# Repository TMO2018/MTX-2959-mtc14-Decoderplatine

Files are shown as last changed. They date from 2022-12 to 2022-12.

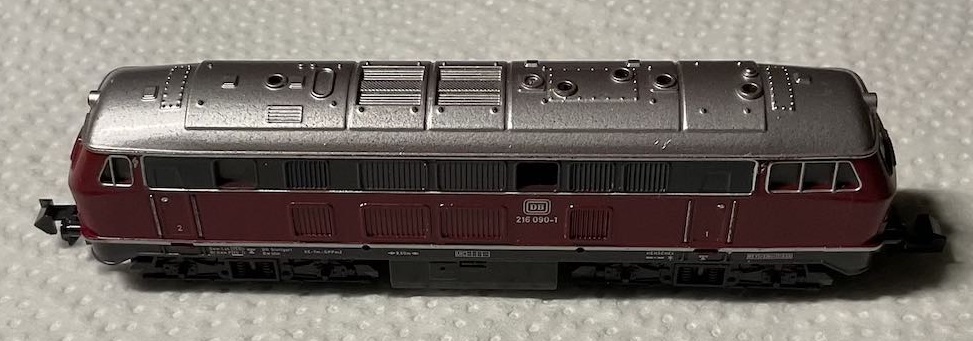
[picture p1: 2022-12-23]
kicad/Rev1_0/doc/pic/1.jpg

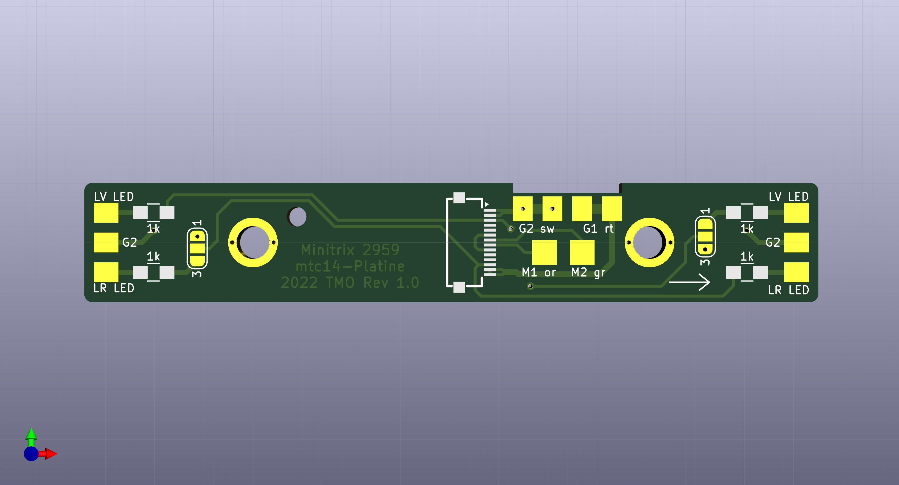
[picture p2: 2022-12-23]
kicad/Rev1_0/pic/front.jpg

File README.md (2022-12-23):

# MTX-2959-mtc14-Decoderplatine
Minitrix 2959 Decoderplatine mit mtc14-Schnittstelle

In diesem Projekt ist eine Digitalplatine mit mtc14-Digitalschnittstelle für die Minitrix Diesellok BR 216 090-1 (2959) beschrieben.
Diese Platine ersetzt 1:1 die vorhandene Platine und bietet zusätzlich eine Möglichkeit zum Anschluß von LED’s für Front- und Rückbeleuchtung.

Die Gerberdateien zur Herstellung der Platine befinden sich im kicad-Ordner (zip-Datei).







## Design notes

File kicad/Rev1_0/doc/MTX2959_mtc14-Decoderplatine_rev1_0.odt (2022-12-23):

MTX 2959 mtc14-Decoderpaltine Rev. 1.0

Beschreibung

# Einführung

In diesem Projekt ist eine Digitalplatine mit mtc14-Digitalschnittstelle für die Minitrix Diesellok BR 216 090-1 (2959) beschrieben.

Diese Platine ersetzt 1:1 die vorhandene Platine und bietet zusätzlich eine Möglichkeit zum Anschluß von LED’s für Front- und Rückbeleuchtung.

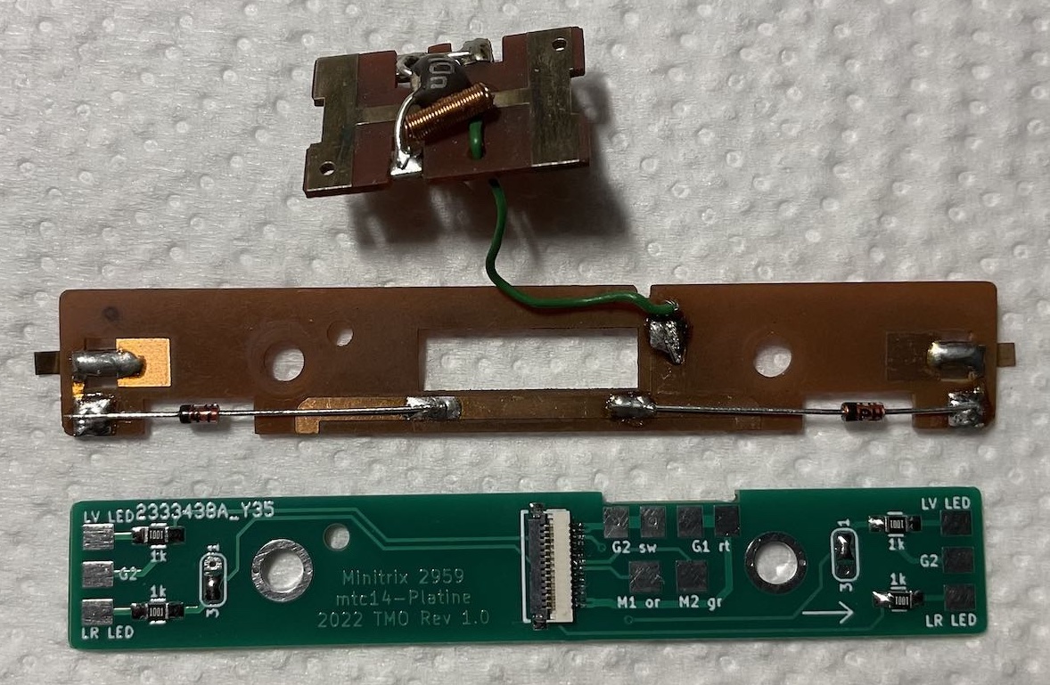
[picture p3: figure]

Achtung:

Die Platinendicke muß 1,0 mm betragen !

# Einbau

Es ist notwendig den Motor mit Litzen an die Lötpunkte M1 und M2 anzuschließen. Die Drossel kann in der Regel verbleiben. Wichtig ist dabei, dass zwischen Motor und Chasis sowie sonstigen leitfähigen Teilen keine Verbindungen bestehen.

Die Gleisspannung wird an den Lötpunkten G1 und G2 angeschlossen. G2 wird bei dieser Lok über die Achsen der Drehgestelle auf das Metallchassis und über die Schraubbefestigung auf die Platine übertragen.

Die kleine Platine aus dem Bodenbereich des Chassis wird weiterhin zur Stromversorgung genutzt. Anschluß an Lötpunkt G1. Ggf. ist der Kondensator je nach Regelverhalten der Decoders zu entfernen.

G2 ist mit dem Metallchassis verbunden.

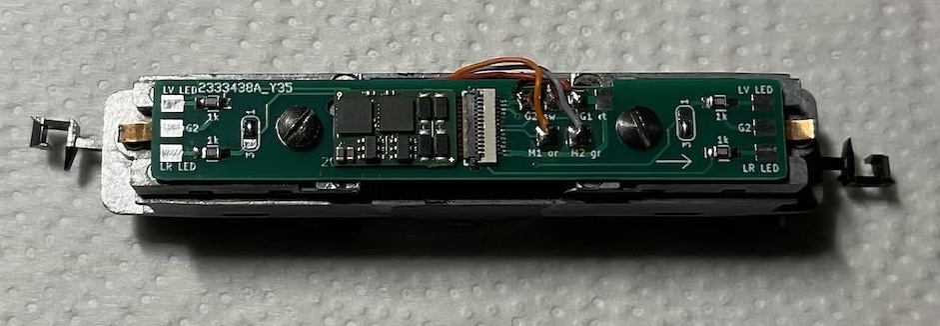
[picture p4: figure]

Lok mit Originalbeleuchtung


# Beleuchtung

Original:

Auf der Unterseite der Digitalplatine befinden sich rechts und links je eine Lötfläche an denen Metallzungen angelötet werden können um die vorhandene Glühlampen weiterhin zu nutzen,

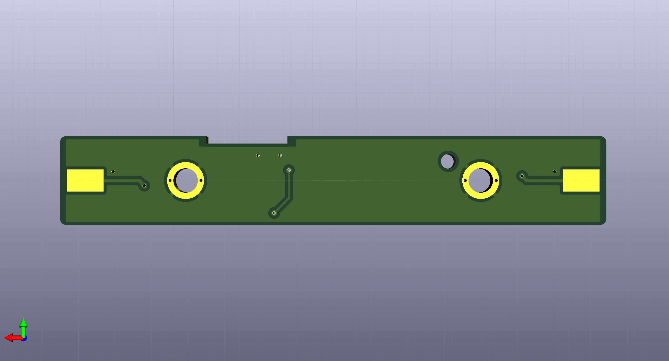
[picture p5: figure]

LED:

Falls die Originalbeleuchtung durch LED ersetzt wird, befinden sich auf der Oberseite der Digitalplatine Lötpunkte für Vorwärts- (LV) und Rückwärtsfahrt (LR). G2 ist der gemeinsame Rückleiter.


Mit den Löt-Jumpern wird die Beleuchtungs-Varinate ausgewählt.

Löt-Jumper neben Fahrtrichtungspfeil:

Brücke 1 nach Mitte: LED

Brücke 3 nach Mitte: Glühlampen

Löt-Jumper ohne Fahrtrichtungspfeil:

Brücke 1 nach Mitte: Glühlampen

Brücke 3 nach Mitte: LED

BOM

Reference Value Package Manufacturer Part

R1, R2, R3, R4 1k SMD 0805 Widerstand

J1 0.5K-QX-14PWB FPC / FFC HDGC Verbinder

Verbinder J1:

Fahrzeugseitig werden FPC / FFC Verbinder vom Typ AVX 6238 oder ähnlich verwendet. Für die Einhaltung der Norm ist entscheidend, dass die verwendeten Klemmleisten für 0,3 mm starkes Platinenmaterial spezifiziert sind, ein Anschlussraster von 0,5 mm und nur einseitig Kontakte haben.

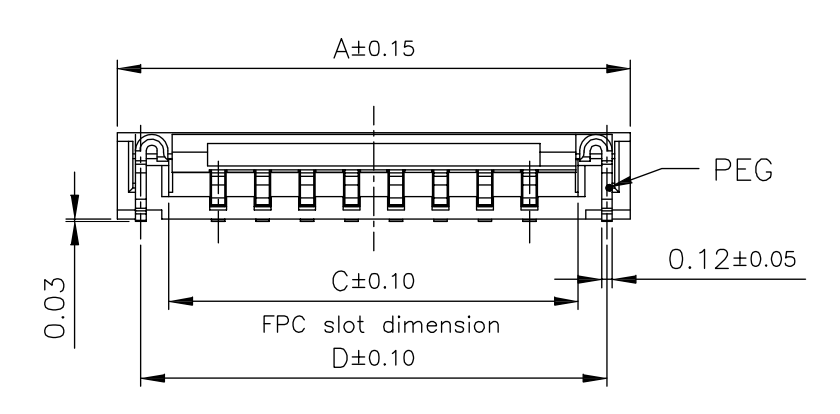
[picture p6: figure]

Das Maß C muß 7,60 mm betragen !

# Verbinder-Spezifikation:

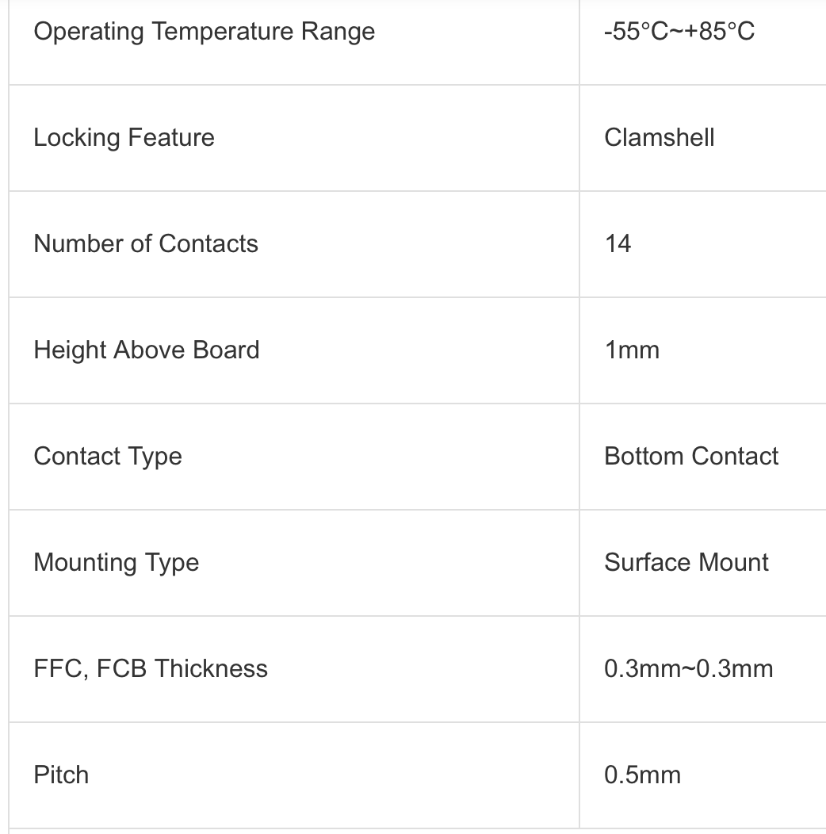
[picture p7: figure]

# Versionsinformation :

Revision 1.0:

Erste Version

MTX2959_mtc14-Decoderplatine_rev1_0.odt 23.12.2022 Page 6 of 6 TMO Version 1.0

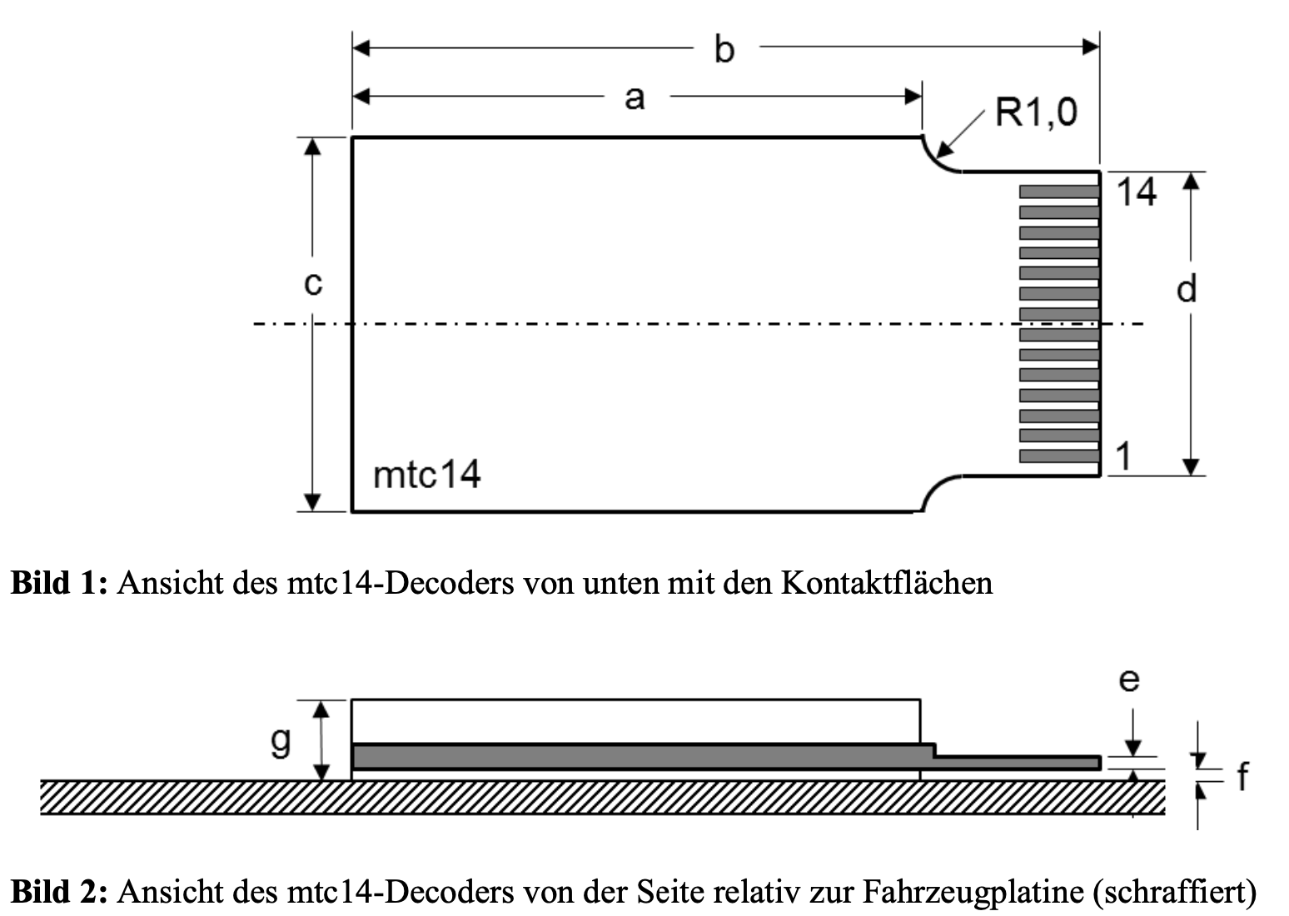
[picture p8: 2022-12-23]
kicad/Rev1_0/pic/mtc14-Decoder.png

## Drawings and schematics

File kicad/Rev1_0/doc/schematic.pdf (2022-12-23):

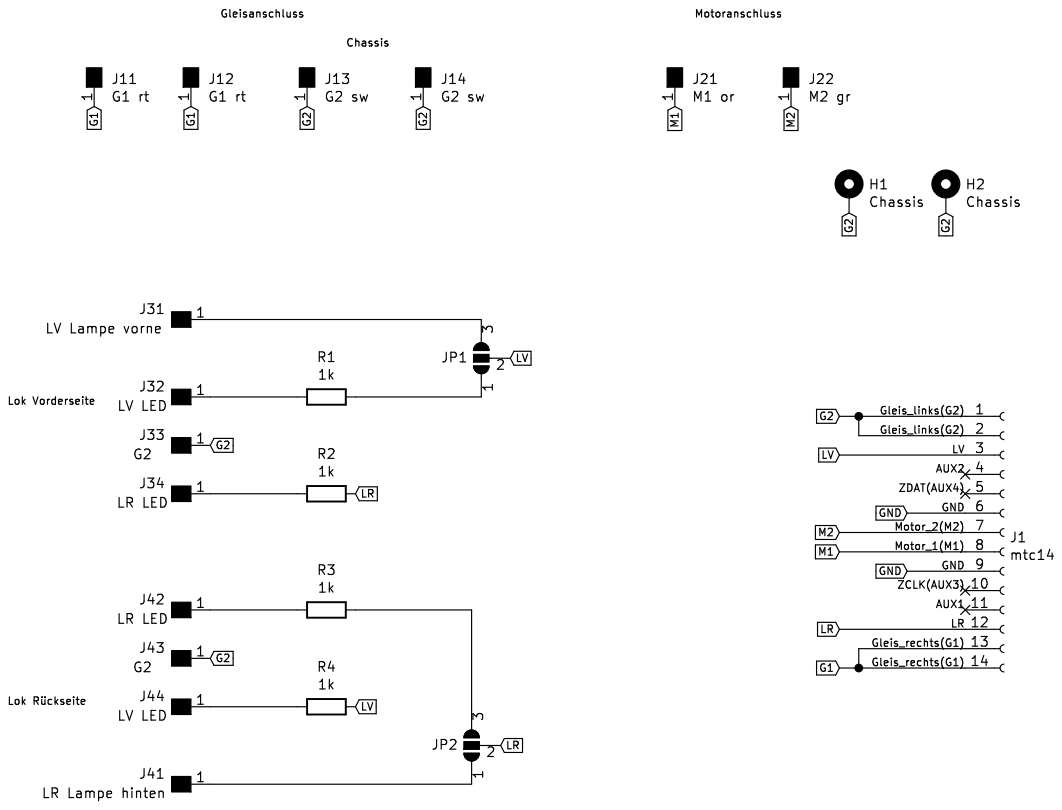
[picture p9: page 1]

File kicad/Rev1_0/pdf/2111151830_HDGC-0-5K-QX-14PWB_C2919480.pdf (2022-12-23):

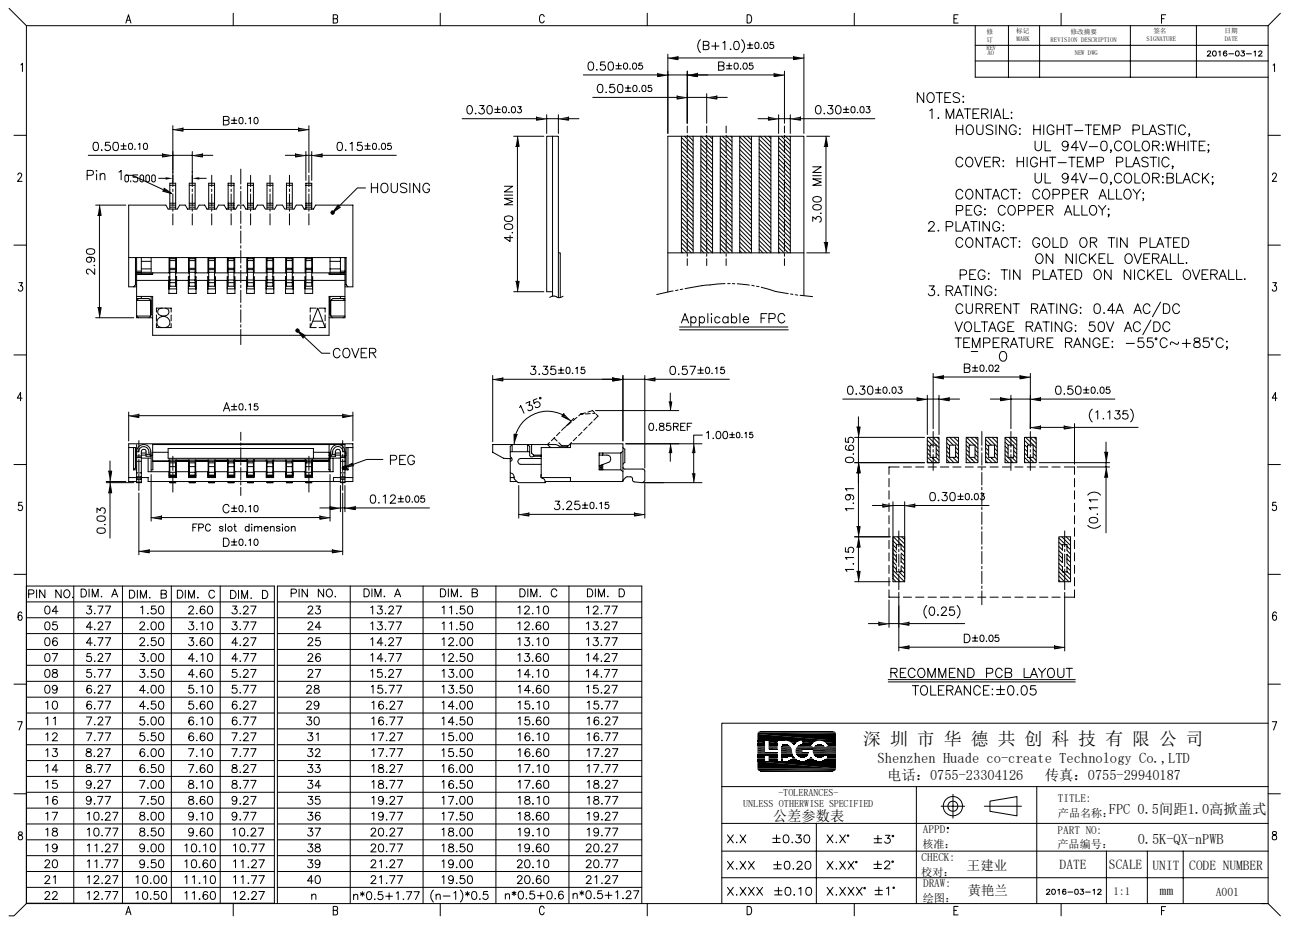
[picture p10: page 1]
0.5K-QX-nPWB; FPC 0.5间距1.0高掀盖式; 公差参数表; APPD: 核准： CHECK: 校对： DRAW:; 修订REV; 标记MARK; 修改摘要 REVISION DESCRIPTION; 签名 SIGNATURE; 日期 DATE Shenzhen Huade co-create Technology Co.,LTD -TOLERANCES- UNLESS OTHERWISE SPECIFIED; mm TITLE: 产品名称： PART NO: 产品编号： AO; NEW DWG 王建业; DATE; SCALE; UNIT; CODE NUMBER 黄艳兰

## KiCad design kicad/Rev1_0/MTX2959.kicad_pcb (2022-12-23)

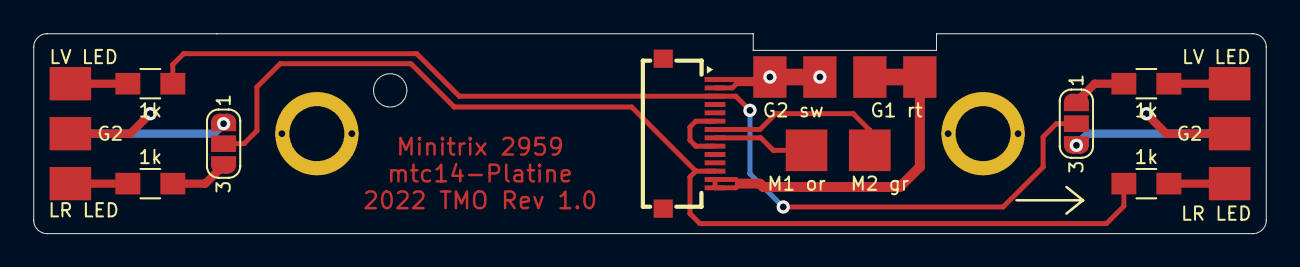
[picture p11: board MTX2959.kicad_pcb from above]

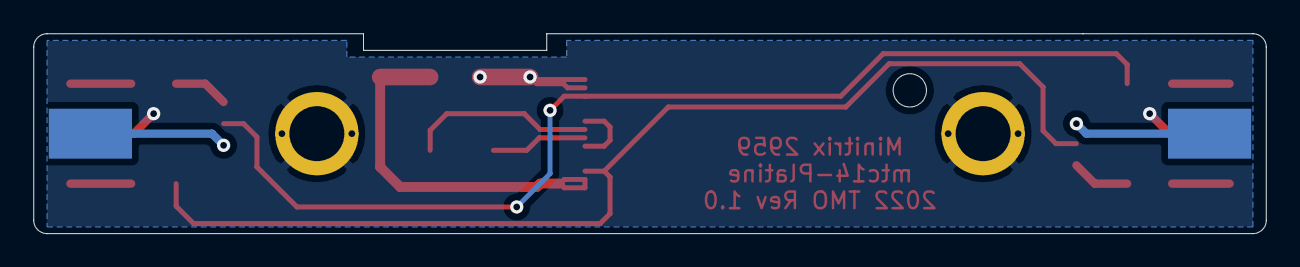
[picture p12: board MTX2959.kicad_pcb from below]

Board: 2 copper layers, 74.0 x 12.0 mm, 23 parts (2 on the bottom side), 15 nets.

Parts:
H1, H2: Chassis; MountingHole_3.3mm_Pad_5mm
J1: mtc14; FPC-SMD_14P-P0.5_HDGC_0.5K-QX-14PWB_HandSoldering_(mtc14)
J11, J12: G1 rt; Measurement_Point_Square-SMD-Pad_Small
J13, J14: G2 sw; Measurement_Point_Square-SMD-Pad_Small
J21: M1 or; Measurement_Point_Square-SMD-Pad_Small
J22: M2 gr; Measurement_Point_Square-SMD-Pad_Small
J31: LV Lampe vorne; Measurement_Point_Square-SMD-Pad_Big
J32, J44: LV LED; Measurement_Point_Square-SMD-Pad_Small
J33, J43: G2; Measurement_Point_Square-SMD-Pad_Small
J34, J42: LR LED; Measurement_Point_Square-SMD-Pad_Small
J41: LR Lampe hinten; Measurement_Point_Square-SMD-Pad_Big
JP1, JP2: SolderJumper_2_Open; SolderJumper-3_P1.3mm_Open_RoundedPad1.0x1.5mm_NumberLabels
R1, R2, R3, R4: 1k; R_0805_HandSoldering

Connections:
G1: J1.13, J1.14, J11.1, J12.1
G2: H1.1, H2.1, J1.1, J1.2, J13.1, J14.1, J33.1, J43.1
GND: J1.6, J1.9
LR: J1.12, JP2.2, R2.1
LV: J1.3, JP1.2, R4.1
M1: J1.8, J21.1
M2: J1.7, J22.1
unnamed: J31.1, JP1.3
unnamed: J32.1, R1.2
unnamed: J34.1, R2.2
unnamed: J41.1, JP2.1
unnamed: J42.1, R3.2
unnamed: J44.1, R4.2
unnamed: JP1.1, R1.1
unnamed: JP2.3, R3.1
